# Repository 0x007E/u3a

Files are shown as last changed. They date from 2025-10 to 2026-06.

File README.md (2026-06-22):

  

# `U3A` - USB/UART/UPDI - Adapter



The `U3A` project is based on a ([FT232](#additional-information)) that ist used as USB (Full Speed) to serial UART transceiver. Most signals of the ([FT232](#additional-information)) are routed to the connector pins `J2` and `J4`. Whithin the DIP switches the adapter can be switched from `UART` to `UPDI` mode to program microcontrollers. It is possible to select between two voltage sources. Either `5V` from USB or `3V3` from the internal LDO on the board.

> The LDO itself can drive around `800 mA`. Therefore it is necessary to install a cooling unit inside the housing. The mount for this is already provided in the housing.

| Experience | Level |
|:---|:-----:|
| Soldering | ?% |
| Mechanical  | ?% |

# Adapter-Boards

| RS232 | RS422 | RS485 |
|:---:|:---:|:-----:|
| Bottom Layer | Bottom Layer | Bottom Layer |
| Schematic | Schematic | Schematic |
| [pdf](https://github.com/0x007E/u3a_rs232/releases/latest/download/schematic.pdf) / [cadlab](https://cadlab.io/project/29701/main/files) | [pdf](https://github.com/0x007E/u3a_rs422/releases/latest/download/schematic.pdf) / [cadlab](https://cadlab.io/project/29767/main/files) | [pdf](https://github.com/0x007E/u3a_rs485/releases/latest/download/schematic.pdf) / [cadlab](https://cadlab.io/project/29763/main/files) |
| [GitHub](https://github.com/0x007e/u3a_rs232) | [GitHub](https://github.com/0x007e/u3a_rs422) | [GitHub](https://github.com/0x007e/u3a_rs485) |

# Downloads

| Type | File | Description |
|:---:|:---:|:---|
| Schematic | [pdf](https://github.com/0x007E/u3a/releases/latest/download/schematic.pdf) / [cadlab](https://cadlab.io/project/29697/main/files) | Schematic files |
| Board | [pdf](https://github.com/0x007E/u3a/releases/latest/download/pcb.pdf) / [cadlab](https://cadlab.io/project/29697/main/files) | Board file |
| Drill | [pdf](https://github.com/0x007E/u3a/releases/latest/download/drill.pdf) | Drill file |
| BoM | [xlsx](https://github.com/0x007E/u3a/releases/latest/download/bom.xlsx) / [html](https://github.com/0x007E/u3a/releases/latest/download/ibom.html) | Bill of Material as Excel/interactive HTML |
| PCB | [zip](https://github.com/0x007E/u3a/releases/latest/download/kicad.zip) / [tar](https://github.com/0x007E/u3a/releases/latest/download/kicad.tar.gz) | KiCAD/Gerber/BoM/Drill files |
| Mechanical | [zip](https://github.com/0x007E/u3a/releases/latest/download/freecad.zip) / [tar](https://github.com/0x007E/u3a/releases/latest/download/freecad.tar.gz) | FreeCAD/Housing and PCB (STEP/STL) files |

# Hardware

There are two parts of the hardware. The pcb and the housing of the `U3A`. The pcb is created with [KiCAD](#additional-information) and the housing with `FreeCAD`. All files are built with `github actions` so that they are ready for a production environment. The housing is printed with a 3D-printer (`Dremel 3D40`).

## PCB

The circuit board is populated on both sides (Top, Bottom). The best way for soldering the `SMD` components is within a vapor phase soldering system and for the `THT` components with a standard soldering system.

### Top Layer

Top Layer

### Bottom Layer

Bottom Layer

## Mechanical

The housing has a tolerance of `0.2mm` on each side of the case. So the pcb should fit perfectly in the housing. The tolerance can be modified with `FreeCAD` in the `Parameter` Spreadsheet.

### Assembled

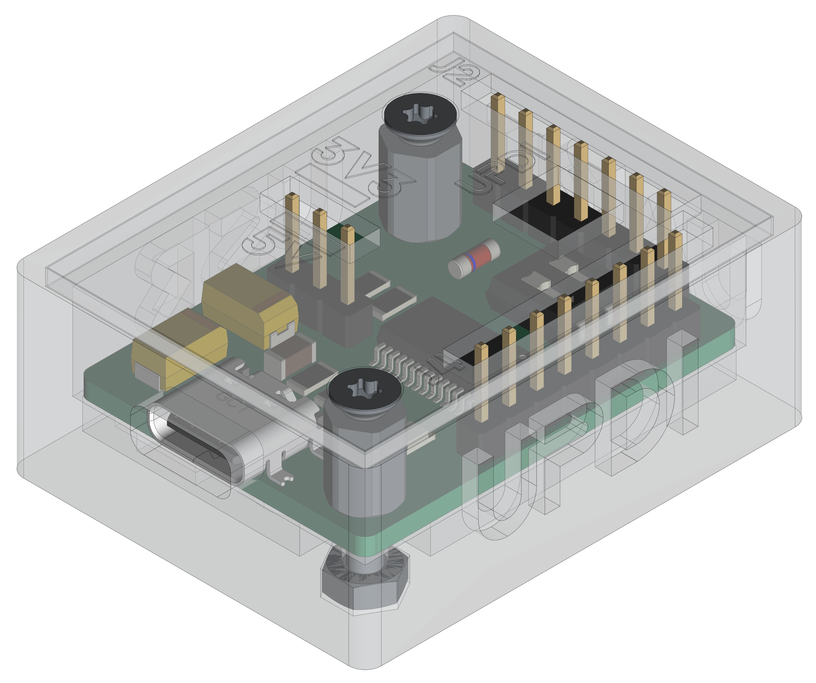
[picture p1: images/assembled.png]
Assembled


### Exploded

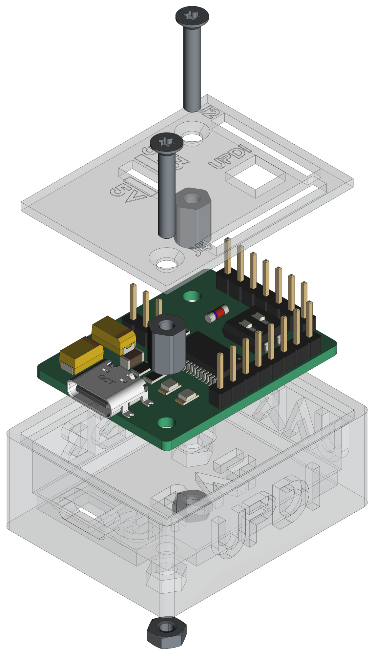
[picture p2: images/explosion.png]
Exploded


# Connection/Setup

The `U3A` is powerd over USB with `5V`. The voltage of the pins can be setup through jumper `J1`. Either `5V` or `3V3`. The output of the system is driven by `CBUS4`. It needs to be configured through [FT_PROG](#additional-information). Mostly pins of the IC are routed to the connectors `J2` and `J4`

| CBUS | Value | Description |
|:----:|:---|:---|
| 0 | TXLED# | Transmit signal LED pin |
| 1 | RXLED# | Receive signal LED pin |
| 2 | TXDEN/SLEEP#  | Depends on external module (`u3a_rs422`/`_rs485`) |
| 3 | PWREN# | Drive external hardware (`u3a_rs422`/`_rs485`) |
| 4 | PWREN# | Drive external `VCC` pins with selected voltage |

## Simple loopback setup for testing purpose

``` bash
#
#               +-----------------------------------+      +---------------------+
#               |J2     U                       +---+---+  |                     |
#            +--+--+    S                       |  USB  |--+ +-----------------+ |
#            | VCC |    B      UPDI             +---+---+  | | TeraTerm        | |
#            | GND |    /    +---+---+              |      | | ~~~~~~~~        | |
#            | PDI |    U    |   |   |              |      | | ~~~~~           | |
#            | CTS |    A    |   |   |              |      | | ~~~~~~~~~~~~    | |
#      L     | RTS |    R    | X | X |              |      | |                 | |
#      O +---+ TXD |    T    +---+---+     +-+      |      | +-----------------+ |
#      O +---+ RXD |    /                 / /       |      |                     |
#      P     +-----+    U               +-+-+-+-+-+-+      | Computer            |
#      B        |       P               | 5V  | 3V3 |      |                     |
#      A        |       D               +-----+-----+      +---------------------+
#      C        |  J4   I                           |
#      K        | +---+---+---+---+---+---+---+---+ |
#               | | V | C | C | D | D | D | R | G | |
#               +-+ C | B | B | C | T | C | I | N +-+
#                 | C | 3 | 2 | D | R | R |   | D |
#                 +---+---+---+---+---+---+---+---+
```

# Errata/Errors

On some `FT232RL` (NRND) a usb-connection issue occurs if the volatge jumper (`J1`) is set to `3V3`. To solve this issue remove jumper `J1` before the usb-port is connected to a computer and reinsert the jumper `J1` after the connection between the computer and `FT232` is initiated. Details can be found [here](https://github.com/0x007E/u3a/issues/1).

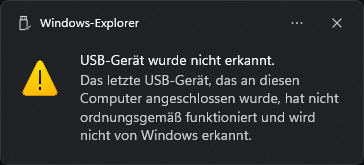
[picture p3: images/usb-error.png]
USB-error


# Additional Information

| Type | Link | Description |
|:---:|:---:|:---|
| FT232R | [pdf](https://ftdichip.com/wp-content/uploads/2020/08/DS_FT232R.pdf) | USB to serial UART interface IC |
| FT_PROG | [web](https://ftdichip.com/utilities/#ft_prog) | EEPROM programming utility for use with FTDI devices |
| KiCAD | [web](https://www.kicad.org/) | KiCAD project page |
| FreeCAD | [web](https://www.freecad.org/) | FreeCAD project page |

---

R. GAECHTER

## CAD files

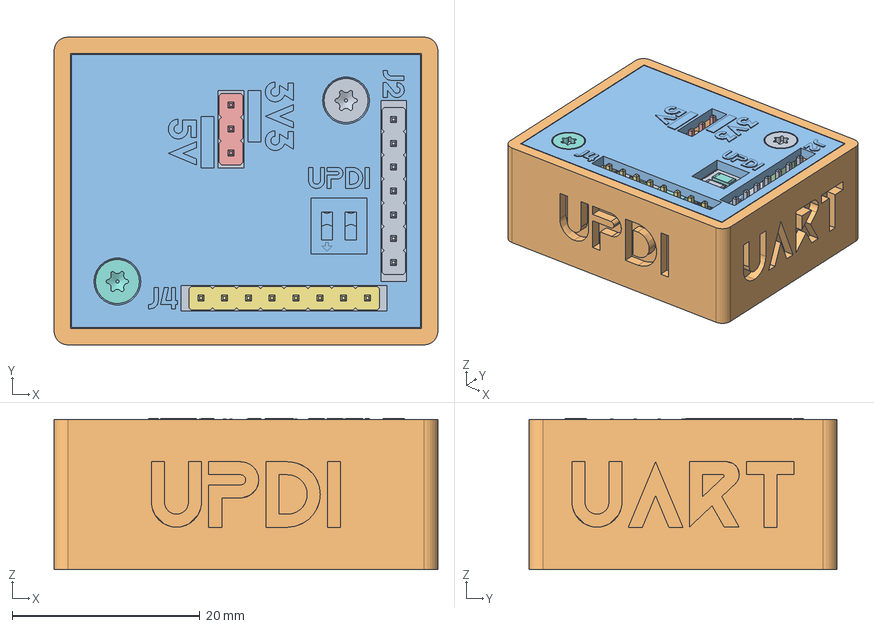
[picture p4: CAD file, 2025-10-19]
mechanical/housing.FCStd
40.9 x 32.8 x 16.1 mm
Pcb_bd1d
C2_CP_EIA_6032_28_Kemet_C_64da7fdd45a4
SW1_SW_DIP_SPSTx02_Slide_67x664mm_W861mm_P254mm_LowProfile_37da67929eb4
R9_R_1206_3216Metric_34e7dffccf68
C3_C_1206_3216Metric_3d514d8e478f
D2_LED_1206_3216Metric_8785e4dcb18a
J4_PinHeader_1x08_P254mm_Vertical_36e3868fe61d
R2_R_1206_3216Metric_dc2d911ed275
J2_PinHeader_1x07_P254mm_Vertical_e5fd038025c4
R11_R_1206_3216Metric_33ffb7d1af25
D1_D_MiniMELF_Standard_bcd0af23464c
D3_LED_1206_3216Metric_163b68126955
J1_PinHeader_1x03_P254mm_Vertical_cb7ea6a1a0e3
C5_CP_EIA_6032_28_Kemet_C_530a06544753
USB4110-GF-A_PART1
U2_SSOP_28_53x102mm_P065mm_a6ff13a3edce
R1_R_1206_3216Metric_ffdeb43b1d05
C7_C_1206_3216Metric_a2ebad5f0eff
R14_R_1206_3216Metric_4367f0e5296a
R10_R_1206_3216Metric_6c93adaee275
R12_R_1206_3216Metric_de12c81666a2
C6_C_1206_3216Metric_aa0f03178b4f
C8_C_1206_3216Metric_1f635bd372b2
R4_R_1206_3216Metric_b2572de6a9d6
R5_R_1206_3216Metric_7e947cd347d0
C1_C_1206_3216Metric_3484ceaeffd0
R3_R_1206_3216Metric_5b0efca3e73b
FB1_L_1206_3216Metric_a91848672457
C4_C_1206_3216Metric_e73e823ad868
R6_R_1206_3216Metric_9da8d51177e2
R7_R_1206_3216Metric_9317204b27e0
98f8d7e1-9c39-11ed-93f0-dde97e994e83_part
98f8d7e2-9c39-11ed-93f0-dde97e994e83_part
98f8d7e3-9c39-11ed-93f0-dde97e994e83_part
98f8d7e3-9c39-11ed-93f0-dde97e994e83_part001
98f8d7e3-9c39-11ed-93f0-dde97e994e83_part002
C9_C_1206_3216Metric_78f7b6b3f625
R13_R_1206_3216Metric_4dd3c09d01d9
R8_R_1206_3216Metric_aa5d14423091
R15_R_1206_3216Metric_eba16ac66124
Q1_SOT_23_103713e101aa
Case
Acrylglass
M2.5x7x5-Spacer
M2.5x7x5-Spacer001
M2.5-Nut
M2.5-Nut001
M2.5x16-Screw
M2.5x16-Screw001

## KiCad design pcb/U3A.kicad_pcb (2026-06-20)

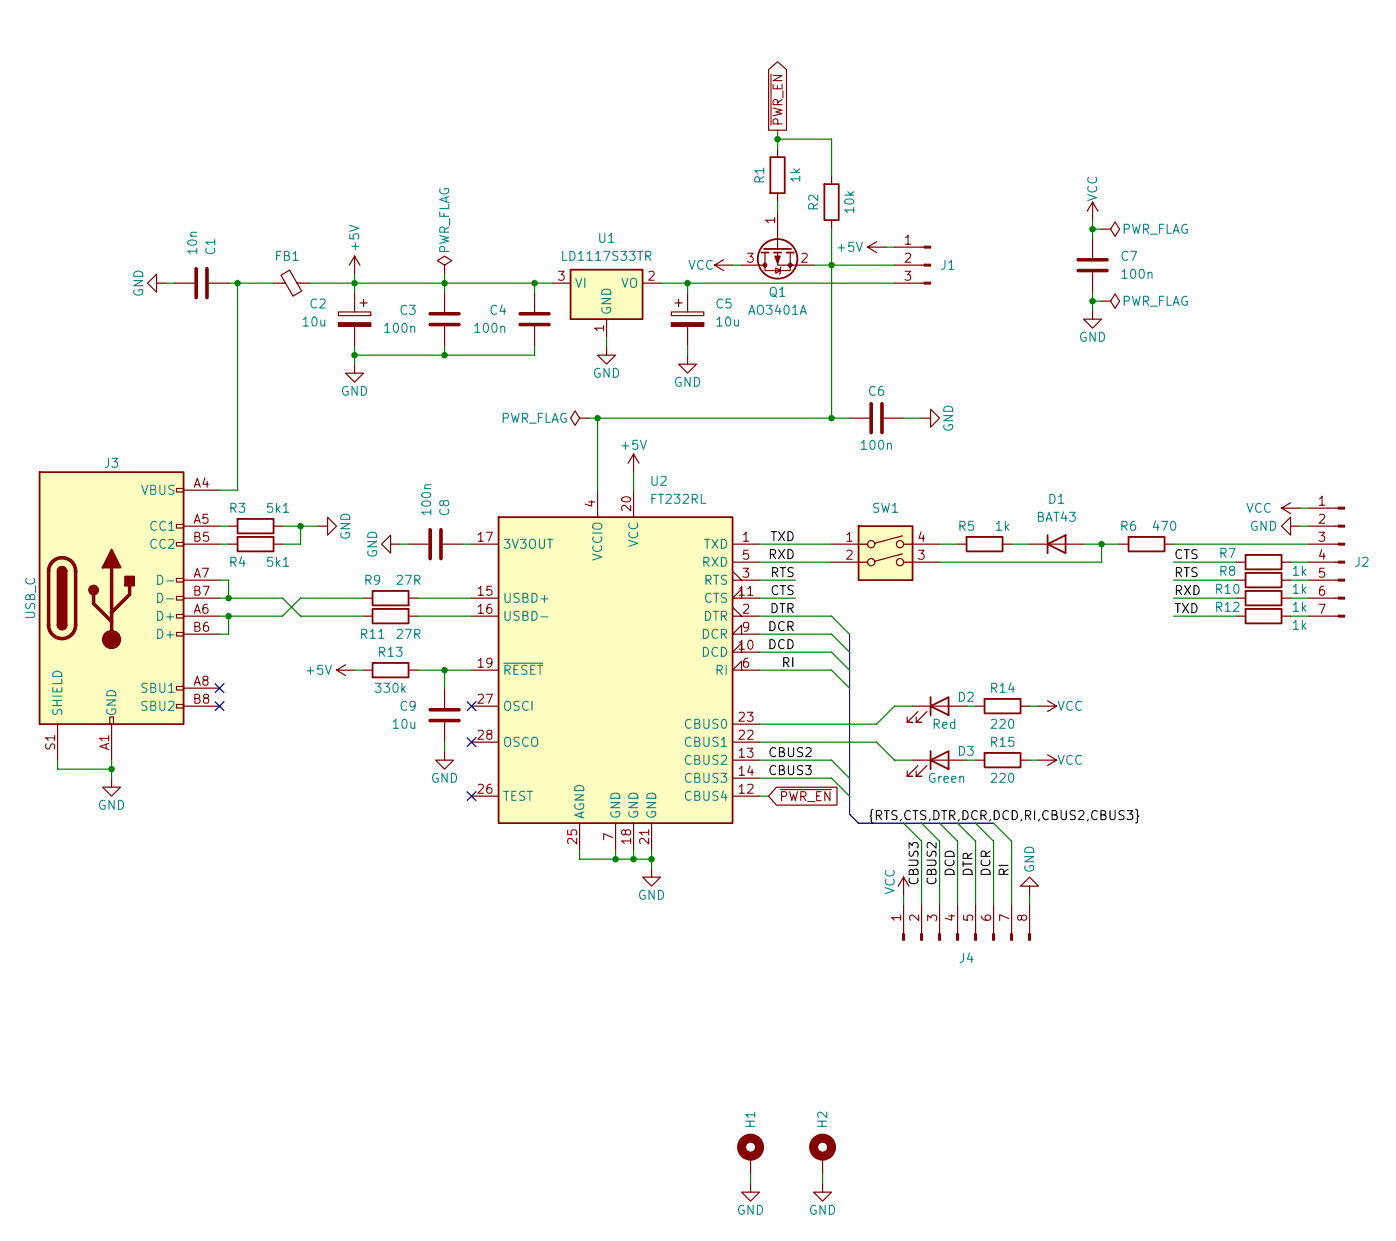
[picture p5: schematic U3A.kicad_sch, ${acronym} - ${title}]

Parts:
C1: 10n; C_1206_3216Metric
C2, C5: 10u; CP_EIA-6032-28_Kemet-C
C3, C4, C6, C7, C8: 100n; C_1206_3216Metric
C9: 10u; C_1206_3216Metric
D1: BAT43; D_MiniMELF
D2: Red; LED_1206_3216Metric
D3: Green; LED_1206_3216Metric
FB1: FerriteBead_Small; L_1206_3216Metric
H1, H2: MountingHole_Pad; MountingHole_2.7mm_M2.5_Pad
J1: Conn_01x03_Pin; PinHeader_1x03_P2.54mm_Vertical
J2: Conn_01x07_Pin; PinHeader_1x07_P2.54mm_Vertical
J3: USB_C; USB_C_Receptacle_GCT_USB4110
J4: Conn_01x08_Pin; PinHeader_1x08_P2.54mm_Vertical
Q1: AO3401A; SOT-23
R1, R5, R7, R8, R10, R12: 1k; R_1206_3216Metric
R2: 10k; R_1206_3216Metric
R3, R4: 5k1; R_1206_3216Metric
R6: 470; R_1206_3216Metric
R9, R11: 27R; R_1206_3216Metric
R13: 330k; R_1206_3216Metric
R14, R15: 220; R_1206_3216Metric
SW1: SW_DIP_x02; SW_DIP_SPSTx02_Slide_6.7x6.64mm_W8.61mm_P2.54mm_LowProfile
U1: LD1117S33TR; TO-252-3_TabPin2
U2: FT232RL; SSOP-28_5.3x10.2mm_P0.65mm

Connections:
+5V: C2.1, C3.2, C4.2, FB1.2, J1.1, R13.2, U1.3 (VI), U2.20 (VCC)
/CBUS2: J4.3, U2.13 (CBUS2)
/CBUS3: J4.2, U2.14 (CBUS3)
/CTS: R7.2, U2.11 (CTS)
/DCD: J4.4, U2.10 (DCD)
/DCR: J4.6, U2.9 (DCR)
/DTR: J4.5, U2.2 (DTR)
/RI: J4.7, U2.6 (RI)
/RTS: R8.2, U2.3 (RTS)
/RXD: R10.2, SW1.2, U2.5 (RXD)
/TXD: R12.2, SW1.1, U2.1 (TXD)
GND: C1.1, C2.2, C3.1, C4.1, C5.2, C6.1, C7.1, C8.1, C9.1, H1.1, H2.1, J2.2, J3.A1 (GND), J3.A12 (GND), J3.B1 (GND), J3.B12 (GND), J3.S1 (SHIELD), J4.8, R3.1, R4.1, U1.1 (GND), U2.7 (GND), U2.18 (GND), U2.21 (GND), U2.25 (AGND)
unnamed: C1.2, FB1.1, J3.A4 (VBUS), J3.A9 (VBUS), J3.B4 (VBUS), J3.B9 (VBUS)
unnamed: D1.2 (A), R6.2, SW1.3
unnamed: D1.1 (K), R5.1
unnamed: D2.2 (A), R14.2
unnamed: D2.1 (K), U2.23 (CBUS0)
unnamed: D3.2 (A), R15.2
unnamed: D3.1 (K), U2.22 (CBUS1)
unnamed: C6.2, J1.2, Q1.2 (S), R2.1, U2.4 (VCCIO)
unnamed: C5.1, J1.3, U1.2 (VO)
unnamed: J2.3, R6.1
unnamed: J2.4, R7.1
unnamed: J2.5, R8.1
unnamed: J2.6, R10.1
unnamed: J2.7, R12.1
unnamed: J3.A5 (CC1), R3.2
unnamed: J3.B5 (CC2), R4.2
unnamed: J3.A6 (D+), J3.B6 (D+), R9.1
unnamed: J3.A7 (D-), J3.B7 (D-), R11.1
unnamed: Q1.1 (G), R1.2
unnamed: R5.2, SW1.4
unnamed: C8.2, U2.17 (3V3OUT)
unnamed: R9.2, U2.15 (USBD+)
unnamed: R11.2, U2.16 (USBD-)
unnamed: C9.2, R13.1, U2.19 (~RESET)
VCC: C7.2, J2.1, J4.1, Q1.3 (D), R14.1, R15.1
~PWR_EN: R1.1, R2.2, U2.12 (CBUS4)

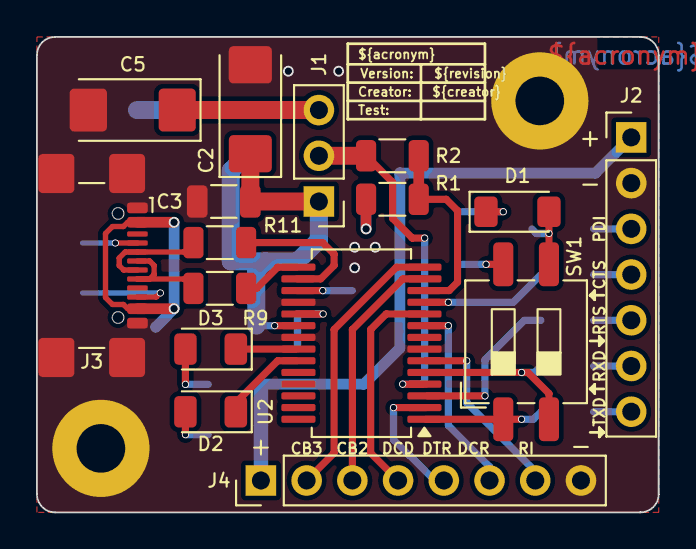
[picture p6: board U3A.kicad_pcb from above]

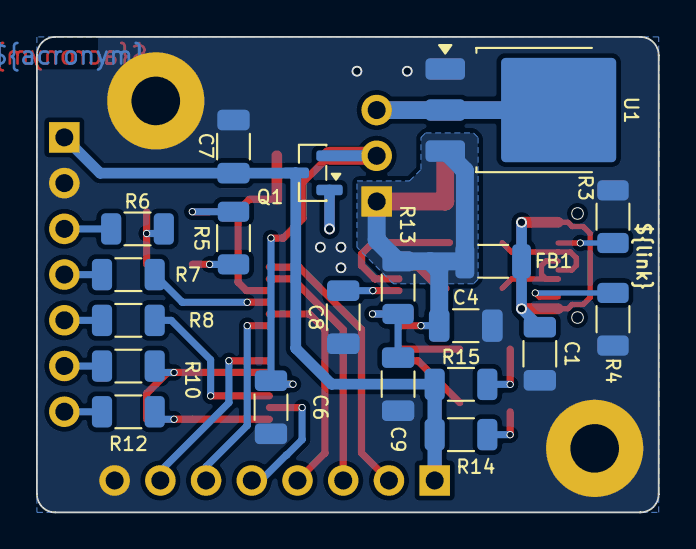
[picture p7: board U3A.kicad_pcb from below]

Board: 2 copper layers, 34.5 x 26.4 mm, 38 parts (20 on the bottom side), 38 nets.

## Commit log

2025-10-20 Change connector name
2025-11-06 Fix wrong vendor-id of device
    [U3A.kicad_pcb, U3A.kicad_sch]
2025-11-13 Fix voltage error on startup
    [U3A.kicad_pcb, U3A.kicad_sch]
2025-12-22 Optimize bottom fabrication layer
    [U3A.kicad_pcb]
2026-01-09 Add CBUS pin description
2026-06-20 Update to KiCAD 9
    [U3A.kicad_pcb, U3A.kicad_sch]
2026-06-20 Rename/Add/Remove bom fields
    [U3A.kicad_pcb, U3A.kicad_sch]
2026-06-20 Fix incorrect adapter schematic links
2026-06-21 Add missing values in bom

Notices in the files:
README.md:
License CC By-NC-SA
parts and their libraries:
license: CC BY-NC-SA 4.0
